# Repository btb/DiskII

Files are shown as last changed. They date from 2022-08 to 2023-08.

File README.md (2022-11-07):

# DiskII
 An Apple Disk II controller clone using standard EPROMs

Revision 0 of this board is broken, [here's how to fix it](https://github.com/btb/DiskII/wiki/Revision-0-errata).

[Revision 1](https://github.com/btb/DiskII/releases/tag/rev1) has all known problems fixed.

[Interactive BOM](https://btb.github.io/DiskII/bom/DiskII_rev1.html)

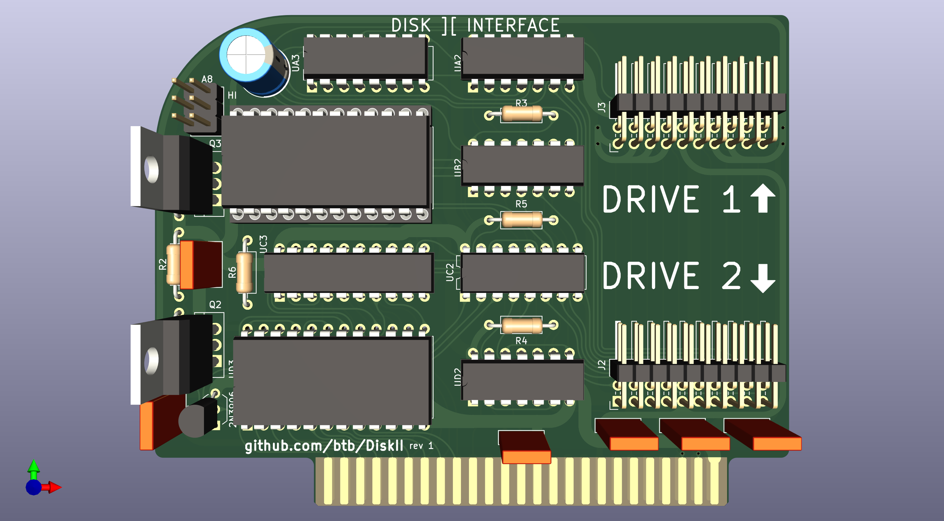
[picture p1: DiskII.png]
image info


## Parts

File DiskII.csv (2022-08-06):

Ref | Qnty | Value | Cmp name | Footprint | Description | Vendor
C1, C3, C4, C5, C6, C7, | 6 | .1uF | C_Small | Capacitor_THT:C_Rect_L7.0mm_W2.0mm_P5.00mm | Unpolarized capacitor, small symbol
C2, | 1 | 22uF | C_Polarized_US | Capacitor_THT:CP_Radial_D8.0mm_P5.00mm | Polarized capacitor, US symbol
J1, | 1 | Apple II Expansion Bus | Conn_02x25_Counter_Clockwise | Apple2:Apple II Expansion Edge Connector | Generic connector, double row, 02x25, counter clockwise pin numbering scheme (similar to DIP packge numbering), script generated (kicad-library-utils/schlib/autogen/connector/)
J2, | 1 | DRIVE 2 | Conn_02x10_Odd_Even_2 | Connector_PinHeader_2.54mm:PinHeader_2x10_P2.54mm_Horizontal | Generic connector, double row, 02x10, odd/even pin numbering scheme (row 1 odd numbers, row 2 even numbers), script generated (kicad-library-utils/schlib/autogen/connector/)
J3, | 1 | DRIVE 1 | Conn_02x10_Odd_Even_1 | Connector_PinHeader_2.54mm:PinHeader_2x10_P2.54mm_Horizontal | Generic connector, double row, 02x10, odd/even pin numbering scheme (row 1 odd numbers, row 2 even numbers), script generated (kicad-library-utils/schlib/autogen/connector/)
Q1, | 1 | 2N3906 | 2N3906 | Package_TO_SOT_THT:TO-92_Inline_Wide | -0.2A Ic, -40V Vce, Small Signal PNP Transistor, TO-92
Q2, Q3, | 2 | MPSU51 | MPSA92_1 | Package_TO_SOT_THT:TO-220-3_Vertical | 0.5A Ic, 300V Vce, PNP High Voltage Transistor, TO-92
R1, | 1 | 150 | R_US | Resistor_THT:R_Axial_DIN0207_L6.3mm_D2.5mm_P7.62mm_Horizontal | Resistor, US symbol
R2, | 1 | 68 | R_US | Resistor_THT:R_Axial_DIN0207_L6.3mm_D2.5mm_P7.62mm_Horizontal | Resistor, US symbol
R3, R7, | 2 | 3K | R_US | Resistor_THT:R_Axial_DIN0207_L6.3mm_D2.5mm_P7.62mm_Horizontal | Resistor, US symbol
R4, | 1 | 1M | R_US | Resistor_THT:R_Axial_DIN0309_L9.0mm_D3.2mm_P12.70mm_Horizontal | Resistor, US symbol
R5, | 1 | 49K | R_US | Resistor_THT:R_Axial_DIN0309_L9.0mm_D3.2mm_P12.70mm_Horizontal | Resistor, US symbol
R6, | 1 | 560 | R_US | Resistor_THT:R_Axial_DIN0207_L6.3mm_D2.5mm_P7.62mm_Horizontal | Resistor, US symbol
SW1, | 1 | A8 | SW_DPDT_x2 | Connector_PinHeader_2.54mm:PinHeader_2x03_P2.54mm_Vertical | Switch, dual pole double throw, separate symbols
SW2, | 1 | A9 | SW_DPDT_x2 | Connector_PinHeader_2.54mm:PinHeader_2x03_P2.54mm_Vertical | Switch, dual pole double throw, separate symbols
SW3, | 1 | A10 | SW_DPDT_x2 | Connector_PinHeader_2.54mm:PinHeader_2x03_P2.54mm_Vertical | Switch, dual pole double throw, separate symbols
UA2, | 1 | 74LS132 | 74LS132 | Package_DIP:DIP-14_W7.62mm | Quad 2-input NAND Schmitt trigger
UA3, | 1 | 74LS174 | 74LS174 | Package_DIP:DIP-16_W7.62mm | Hex D-type Flip-Flop, reset
UB2, | 1 | 74LS05 | 74LS05 | Package_DIP:DIP-14_W7.62mm | Inverter Open Collect
UB3, | 1 | 2758/16 P6 | 2758 | Package_DIP:DIP-24_W15.24mm | OTP EPROM 64 KiBit, [Obsolete 2004-01]
UC2, | 1 | 74LS259 | 74LS259_1 | Package_DIP:DIP-16_W7.62mm | 8-bit addressable latch
UC3, | 1 | 74LS323 | 74LS323 | Package_DIP:DIP-20_W7.62mm | 8-bit Universal Shift/Storage Register
UD2, | 1 | NE556 | NE556_1 | Package_DIP:DIP-14_W7.62mm | Dual Precision Timers, DIP-14/SOIC-14
UD3, | 1 | 2758/16 P5 | 2716 | Package_DIP:DIP-24_W15.24mm | OTP EPROM 64 KiBit, [Obsolete 2004-01]

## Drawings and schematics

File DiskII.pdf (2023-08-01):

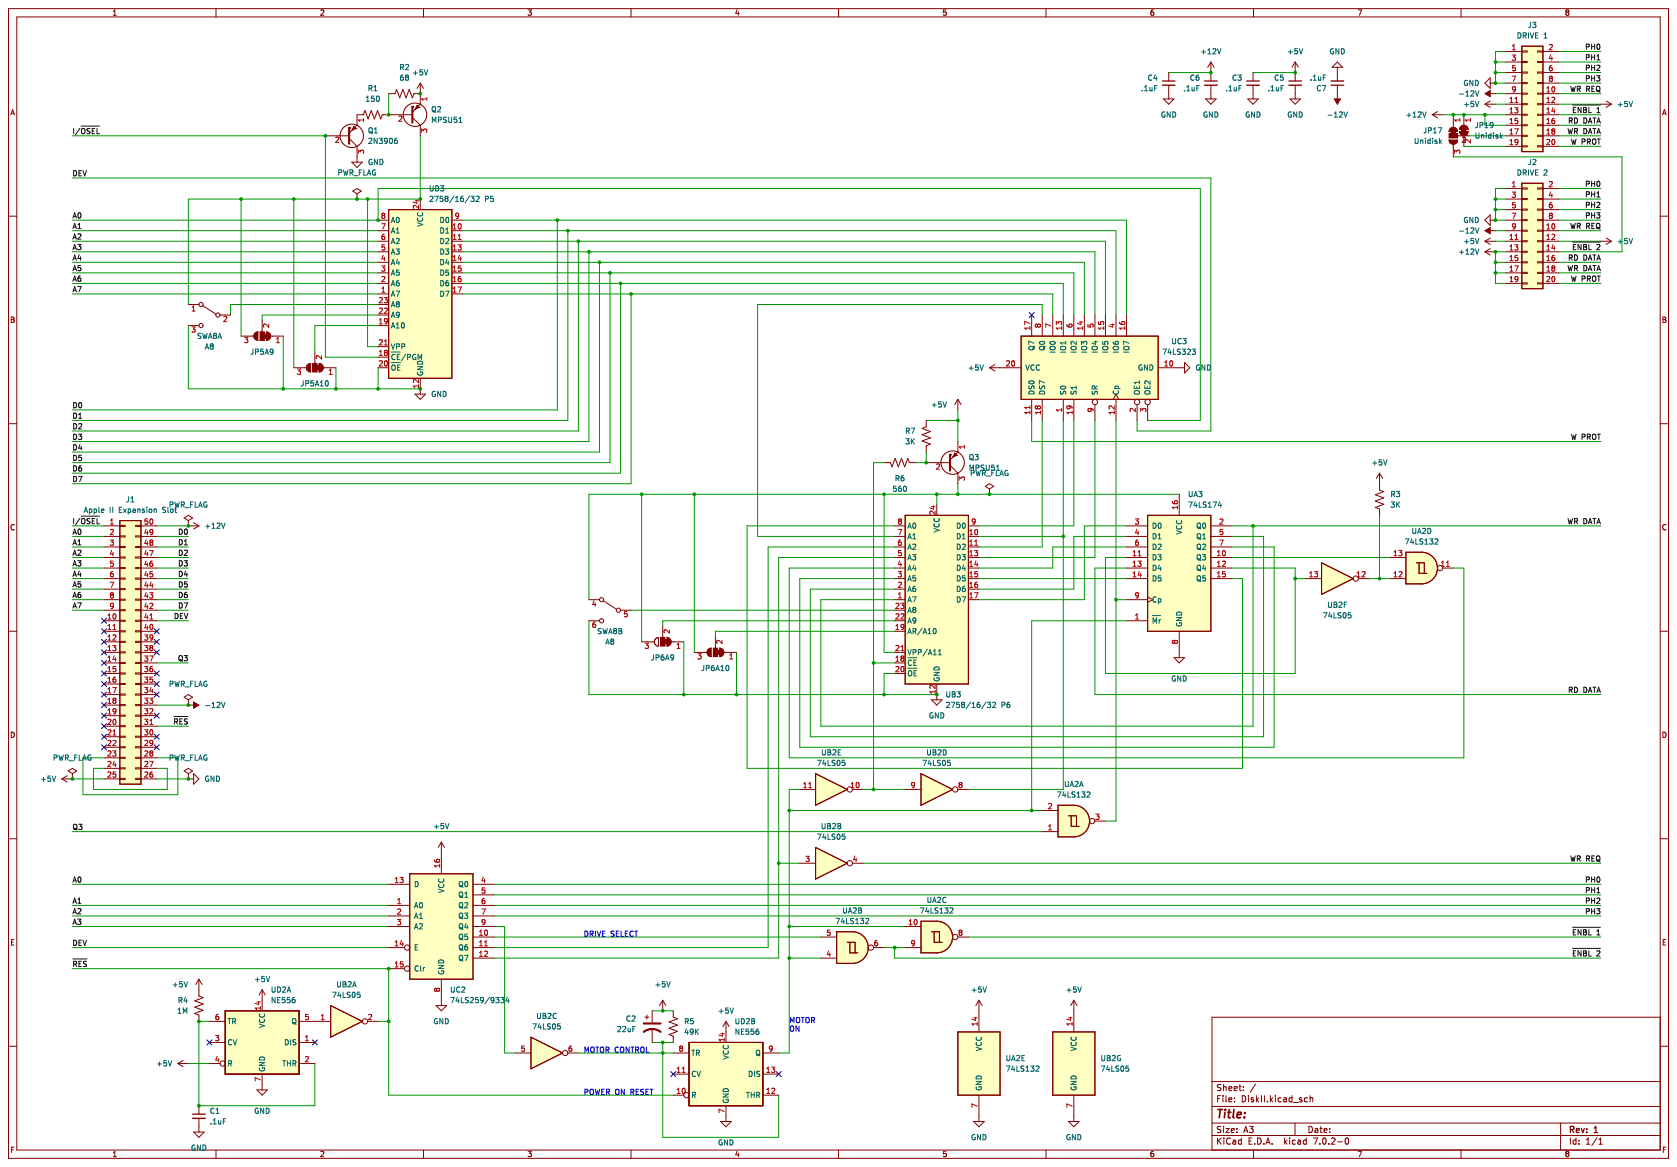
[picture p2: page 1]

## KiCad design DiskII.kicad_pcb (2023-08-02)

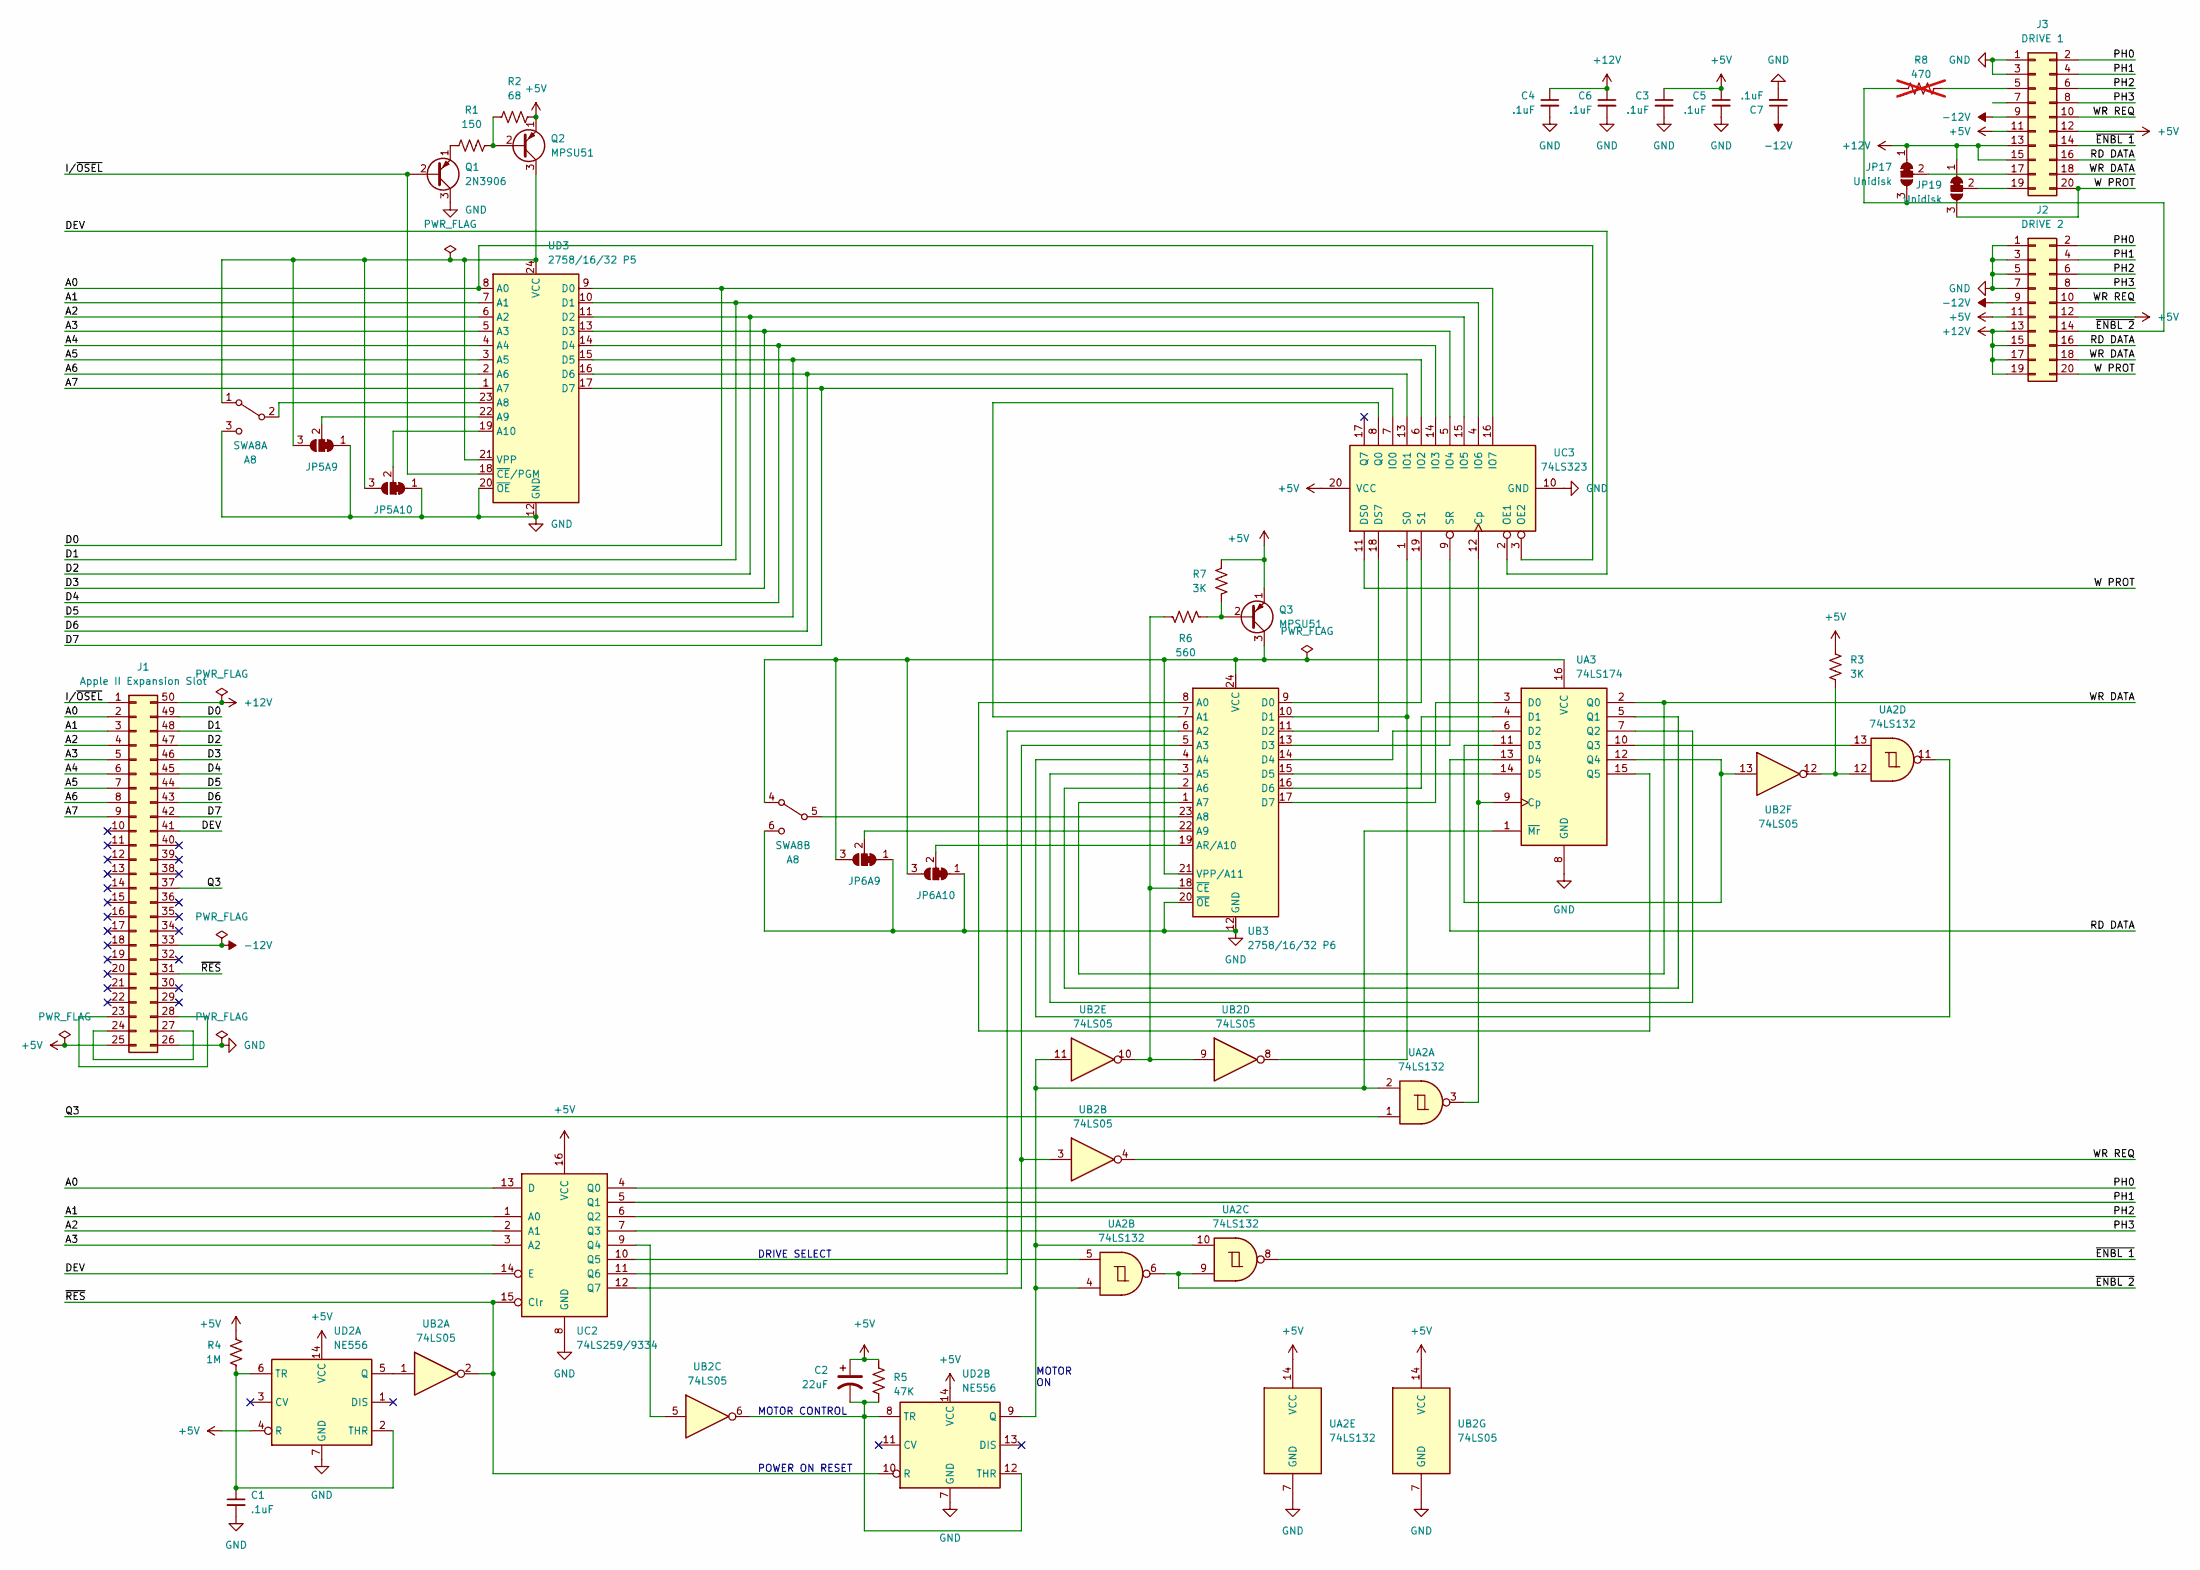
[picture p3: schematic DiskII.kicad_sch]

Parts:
C1, C3, C4, C5, C6, C7: .1uF; C_Rect_L7.0mm_W2.0mm_P5.00mm
C2: 22uF; CP_Radial_D8.0mm_P5.00mm
J1: Apple II Expansion Slot; Apple II Expansion Edge Connector
J2: DRIVE 2; PinHeader_2x10_P2.54mm_Horizontal
J3: DRIVE 1; PinHeader_2x10_P2.54mm_Horizontal
JP5A9, JP6A9: A9; SolderJumper-3_P1.3mm_Bridged12_RoundedPad1.0x1.5mm_NumberL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
JP5A10, JP6A10: A10; SolderJumper-3_P1.3mm_Bridged12_RoundedPad1.0x1.5mm_NumberL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
JP17, JP19: Unidisk; SolderJumper-3_P1.3mm_Bridged12_RoundedPad1.0x1.5mm
Q1: 2N3906; TO-92_Inline_Wide
Q2, Q3: MPSU51; TO-220-3_Vertical
R1: 150; R_Axial_DIN0207_L6.3mm_D2.5mm_P10.16mm_Horizontal
R2: 68; R_Axial_DIN0207_L6.3mm_D2.5mm_P10.16mm_Horizontal
R3, R7: 3K; R_Axial_DIN0207_L6.3mm_D2.5mm_P10.16mm_Horizontal
R4: 1M; R_Axial_DIN0207_L6.3mm_D2.5mm_P10.16mm_Horizontal
R5: 47K; R_Axial_DIN0207_L6.3mm_D2.5mm_P10.16mm_Horizontal
R6: 560; R_Axial_DIN0207_L6.3mm_D2.5mm_P10.16mm_Horizontal
R8: 470; R_Axial_DIN0207_L6.3mm_D2.5mm_P10.16mm_Horizontal; not fitted
SWA8: A8; PinHeader_2x03_P2.54mm_Vertical
UA2: 74LS132; DIP-14_W7.62mm
UA3: 74LS174; DIP-16_W7.62mm
UB2: 74LS05; DIP-14_W7.62mm
UB3: 2758/16/32 P6; DIP-24_W15.24mm
UC2: 74LS259/9334; DIP-16_W7.62mm
UC3: 74LS323; DIP-20_W7.62mm
UD2: NE556; DIP-14_W7.62mm
UD3: 2758/16/32 P5; DIP-24_W15.24mm

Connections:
+5V: C2.1, C3.1, C5.1, J1.25, J2.11, J2.12, J3.11, J3.12, Q2.1 (E), Q3.1 (E), R2.1, R3.1, R4.1, R5.2, R7.1, UA2.14 (VCC), UB2.14 (VCC), UC2.16 (VCC), UC3.20 (VCC), UD2.4 (R), UD2.14 (VCC)
+12V: C4.1, C6.1, J1.50, J2.13, J2.15, J2.17, J2.19, J3.13, J3.15, JP17.1 (A), JP19.1 (A)
-12V: C7.1, J1.33, J2.9, J3.9
/A0: J1.2, UC2.13 (D), UC3.3 (OE2), UD3.8 (A0)
/A1: J1.3, UC2.1 (A0), UD3.7 (A1)
/A2: J1.4, UC2.2 (A1), UD3.6 (A2)
/A3: J1.5, UC2.3 (A2), UD3.5 (A3)
/A4: J1.6, UD3.4 (A4)
/A5: J1.7, UD3.3 (A5)
/A6: J1.8, UD3.2 (A6)
/A7: J1.9, UD3.1 (A7)
/D0: J1.49, UC3.16 (IO7), UD3.9 (D0)
/D1: J1.48, UC3.4 (IO6), UD3.10 (D1)
/D2: J1.47, UC3.15 (IO5), UD3.11 (D2)
/D3: J1.46, UC3.5 (IO4), UD3.13 (D3)
/D4: J1.45, UC3.14 (IO3), UD3.14 (D4)
/D5: J1.44, UC3.6 (IO2), UD3.15 (D5)
/D6: J1.43, UC3.13 (IO1), UD3.16 (D6)
/D7: J1.42, UC3.7 (IO0), UD3.17 (D7)
/DEV: J1.41, UC2.14 (E), UC3.2 (OE1)
/I/~OSEL: J1.1, Q1.2 (B), UD3.18 (~CE/PGM)
/PH0: J2.2, J3.2, UC2.4 (Q0)
/PH1: J2.4, J3.4, UC2.5 (Q1)
/PH2: J2.6, J3.6, UC2.6 (Q2)
/PH3: J2.8, J3.8, UC2.7 (Q3)
/Q3: J1.37, UA2.1
/RD DATA: J2.16, J3.16, UA3.13 (D4)
/W PROT: J2.20, J3.20, JP19.3 (B), UC3.11 (DS0)
/WR DATA: J2.18, J3.18, UA3.2 (Q0), UB3.1 (A7)
/WR REQ: J2.10, J3.10, UB2.4
/~ENBL 1: J3.14, UA2.8
/~ENBL 2: J2.14, JP17.3 (B), R8.1, UA2.6, UA2.9
/~RES: J1.31, UB2.2, UC2.15 (Clr), UD2.10 (R)
GND: C1.2, C3.2, C4.2, C5.2, C6.2, C7.2, J1.26, J2.1, J2.3, J2.5, J2.7, J3.1, J3.3, J3.5, J3.7, JP5A9.1 (A), JP5A10.1 (A), JP6A9.1 (A), JP6A10.1 (A), Q1.3 (C), R8.2, SWA8.3 (C), SWA8.6 (C), UA2.7 (GND), UA3.8 (GND), UB2.7 (GND), UB3.12 (GND), UB3.20 (~OE), UC2.8 (GND), UC3.10 (GND), UD2.7 (GND), UD3.12 (GND), UD3.20 (~OE)
unnamed: JP5A9.3 (B), JP5A10.3 (B), Q2.3 (C), SWA8.1 (A), UD3.21 (VPP), UD3.24 (VCC)
unnamed: JP6A9.3 (B), JP6A10.3 (B), Q3.3 (C), SWA8.4 (A), UA3.16 (VCC), UB3.21 (VPP/A11), UB3.24 (VCC)
unnamed: J1.23, J1.28
unnamed: J1.24, J1.27
unnamed: J3.17, JP17.2 (C)
unnamed: J3.19, JP19.2 (C)
unnamed: JP5A9.2 (C), UD3.22 (A9)
unnamed: JP5A10.2 (C), UD3.19 (A10)
unnamed: JP6A9.2 (C), UB3.22 (A9)
unnamed: JP6A10.2 (C), UB3.19 (AR/A10)
unnamed: Q1.1 (E), R1.1
unnamed: Q2.2 (B), R1.2, R2.2
unnamed: Q3.2 (B), R6.1, R7.2
unnamed: R3.2, UA2.12, UB2.12
unnamed: SWA8.2 (B), UD3.23 (A8)
unnamed: SWA8.5 (B), UB3.23 (A8)
unnamed: UA2.3, UA3.9 (Cp), UC3.12 (Cp)
unnamed: UA3.3 (D0), UB3.17 (D7)
unnamed: UA3.4 (D1), UB3.16 (D6)
unnamed: UA3.6 (D2), UB3.14 (D4)
unnamed: UA3.11 (D3), UA3.12 (Q4), UB2.13
unnamed: UA3.14 (D5), UB3.15 (D5)
unnamed: UA3.5 (Q1), UB3.2 (A6)
unnamed: UA3.7 (Q2), UB3.3 (A5)
unnamed: UA2.13, UA3.10 (Q3)
unnamed: UA3.15 (Q5), UB3.8 (A0)
unnamed: UA2.2, UA2.4, UA2.10, UA3.1 (~Mr), UB2.11, UD2.9 (Q)
unnamed: UB3.7 (A1), UC3.8 (Q0)
unnamed: UB3.6 (A2), UC2.11 (Q6)
unnamed: UB2.3, UB3.5 (A3), UC2.12 (Q7)
unnamed: UA2.11, UB3.4 (A4)
unnamed: UB3.9 (D0), UC3.19 (S1)
unnamed: UB2.8, UB3.10 (D1), UC3.1 (S0)
unnamed: UB3.11 (D2), UC3.18 (DS7)
unnamed: UB3.13 (D3), UC3.9 (SR)
unnamed: R6.2, UB2.9, UB2.10, UB3.18 (~CE)
unnamed: UB2.5, UC2.9 (Q4)
unnamed: UA2.5, UC2.10 (Q5)
unnamed: UB2.1, UD2.5 (Q)
unnamed: C1.1, R4.2, UD2.2 (THR), UD2.6 (TR)
unnamed: C2.2, R5.1, UB2.6, UD2.8 (TR), UD2.12 (THR)

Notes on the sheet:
MOTOR ON
POWER ON RESET
DRIVE SELECT
MOTOR CONTROL

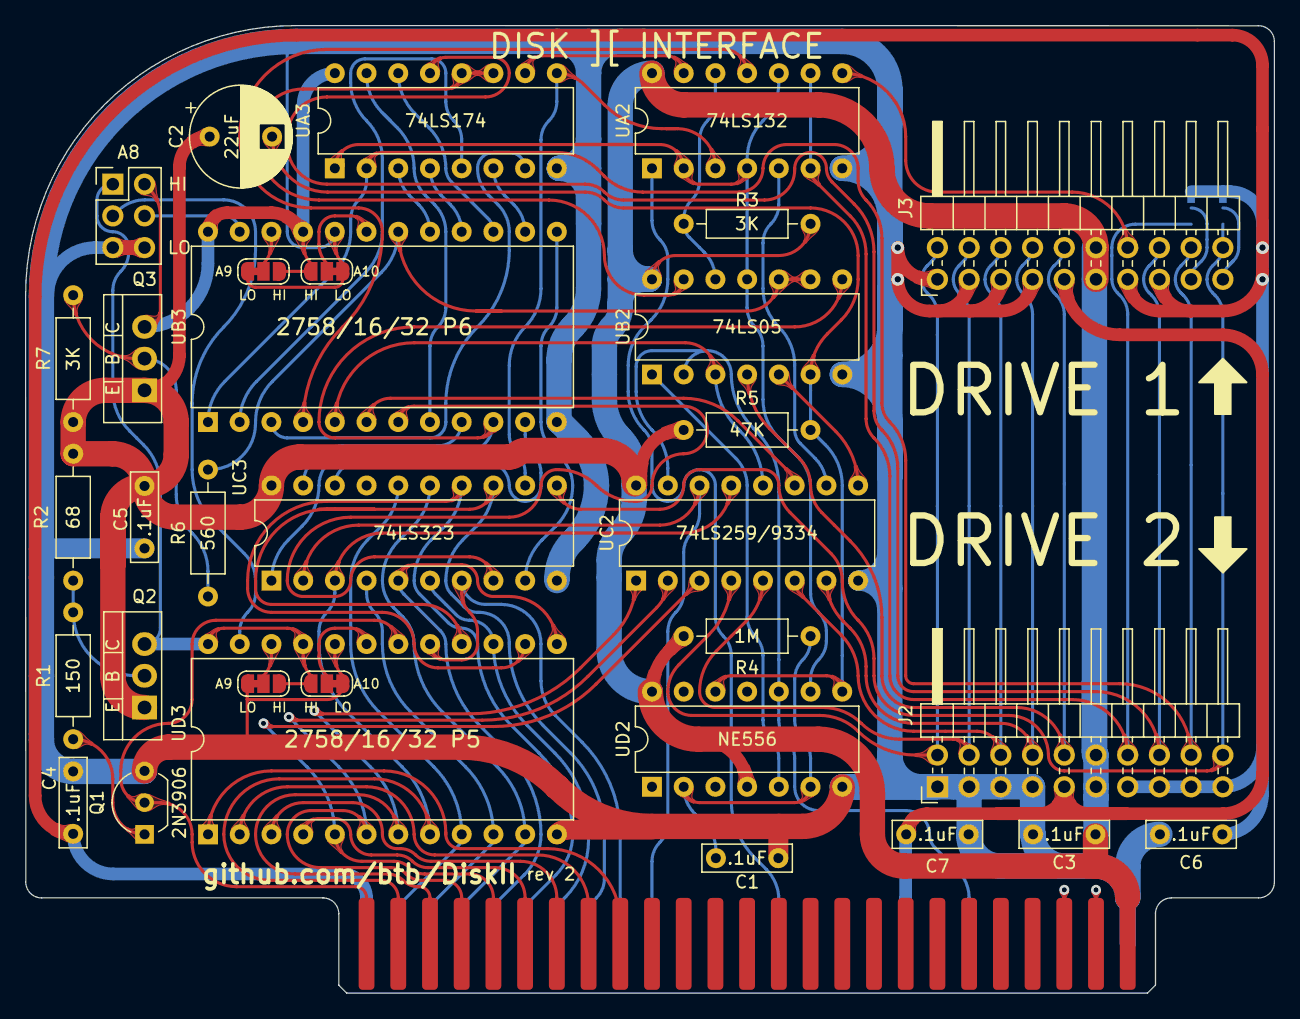
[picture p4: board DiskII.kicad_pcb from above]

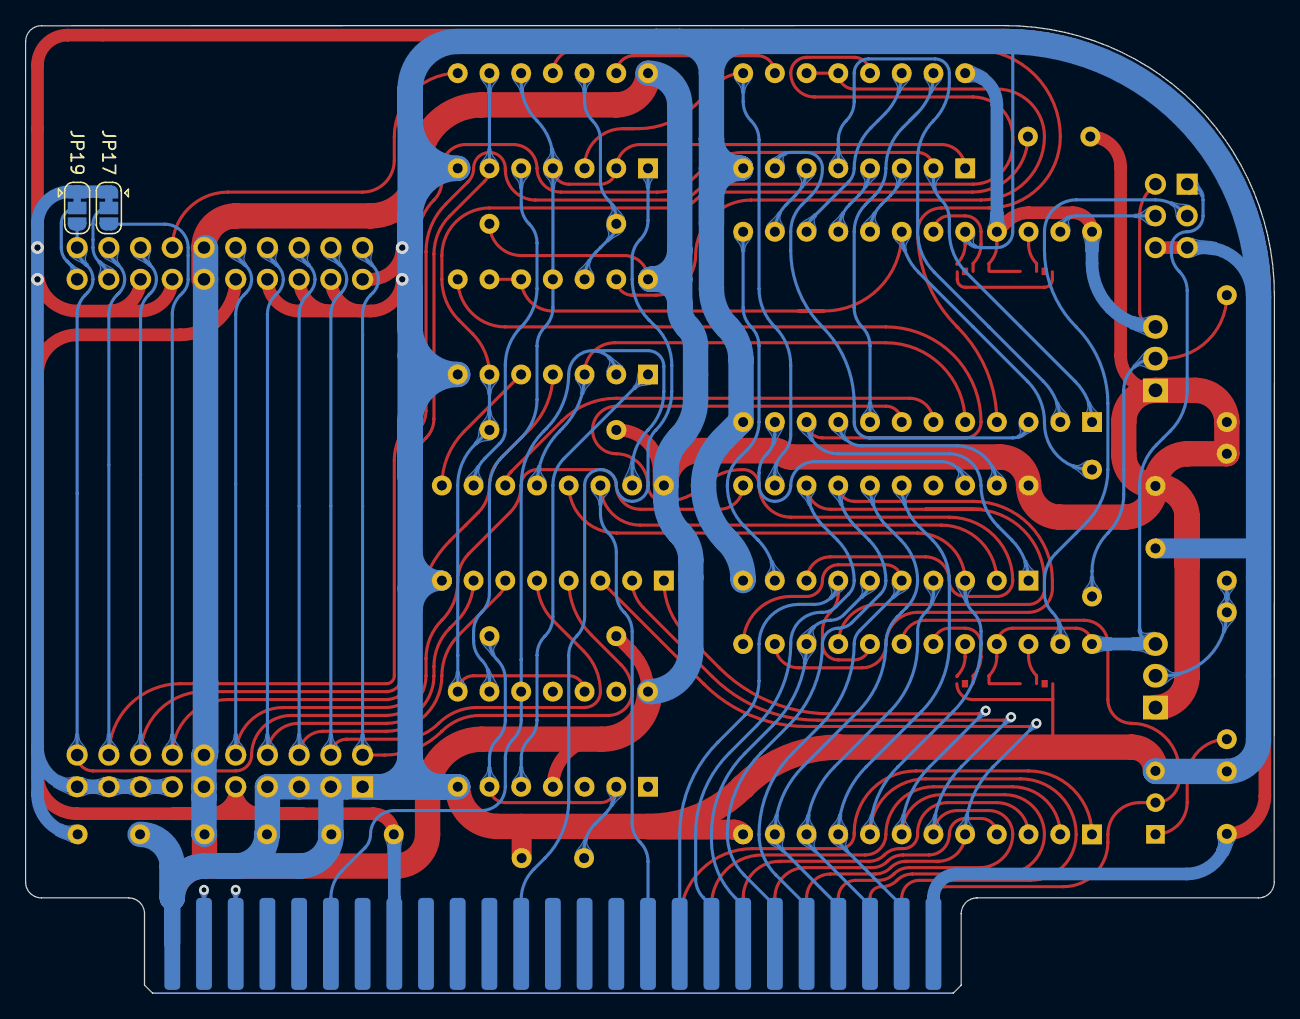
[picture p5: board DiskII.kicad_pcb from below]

Board: 2 copper layers, 100.0 x 77.5 mm, 35 parts (2 on the bottom side), 75 nets.

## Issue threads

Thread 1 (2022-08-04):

Status so far?

mengstr, 2022-08-04:
Hi Bradley,

I just got an Apple // again after 40 years and unfortunately it was without a drive and the disk controller card. (I've already got an Apple drive without the enclosure that I bought by mistake a while back.) So I was just about to make some prototype cards so I could make a clone of the Disk II card myself doing the same as you - using regular eproms which of I have a metric crapton of. But then I saw your card at Adrians Digital Basement on YT and realised that why should I design it myself when there's something already out there.

You mention in the readme that this is a WIP - so I wonder how WIPpy is it? Do you recon It at least kinda works even if some greenwiring would be necessary?

btb, 2022-08-05:
It really should work, it's very close to an exact copy of Apple's card. I simply haven't tested it myself yet due to not yet having a floppy drive or a floppy emulator to plug into it (I'm planning to build an SDisk II) and all of my free time is very limited at the moment.

mengstr, 2022-08-05:
Then I'll give it a go. The only real issue is that the '323 is hard - not to say impossible - to find from any of the usual resellers like Farnell/Element14, Mouser, Digikey or TME. But they're at least available on eBay...

btb, 2022-08-06:
> Then I'll give it a go. The only real issue is that the '323 is hard - not to say impossible - to find from any of the usual resellers like Farnell/Element14, Mouser, Digikey or TME. But they're at least available on eBay...

My favorite seller for items like that is https://unicornelectronics.com

mengstr, 2022-08-06:
They definitely have a lot of nice retro stuff there. But it will end up costing me a bundle in total to get the chips from there, $30 minimum order + overseas shipping, $8 import processing fee and then some local VAT on top of all this.

I found a EU-based (Bulgaria) seller on ebay and got a pack of 10 of the 323's for $6.  Of course I added some USSR variants of the 8080 CPU, and some other interesting 1970's ICs and a tub of 1000 core memory ferrite cores as well ;)

mengstr, 2022-08-27:
I received my PCBs today and soldered up one. I didn't have any 2-row RA connector so a normal one had to suffice. I also jumpered everything related to power save modes and the EPROM banks.

So tomorrow I try find the contents of the eproms and burn them and give it a go in my Apple 2e...  You don't happen to have the eprom bins/hexes available do you?

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

btb, 2022-08-28:
The images are here: https://mirrors.apple2.org.za/Apple%20II%20Documentation%20Project/Interface%20Cards/Disk%20Drive%20Controllers/Apple%20Disk%20II%20Interface%20Card/ROM%20Images/

You can map them into your EPROMs at whatever addresses you like, just set the a8, a9, a10 jumpers accordingly.

veremenko-y, 2022-09-21:
I'm kinda curious about the status of this as well :)

btb, 2022-10-20:
I finally got a real disk drive to test with, and this design does indeed have a fatal flaw. I'll put up some instructions for fixing it.

btb, 2022-10-20:
I've described the problem and how to fix it here:
https://github.com/btb/DiskII/wiki/Revision-0-errata

Closed 2023-04-25.

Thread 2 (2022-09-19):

Files to burn to Eproms and Jumper functions

asapreta, 2022-09-19:
Hi!
Where do I can find the contents for the 2716 Eproms? Are they the same as prom5 and prom6?

Also, what are the jumpers for?

Thank you!

mengstr, 2022-09-21:
I downloaded my images from  https://mirrors.apple2.org.za/Apple%20II%20Documentation%20Project/Interface%20Cards/Disk%20Drive%20Controllers/Apple%20Disk%20II%20Interface%20Card/ROM%20Images/

btb, 2022-09-22:
The jumpers just go directly to your eprom's extra address lines, A8, A9 and A10, and you set them high or low to select the region of the eprom where you have placed the desired firmware.

asapreta, 2022-09-22:
> I downloaded my images from https://mirrors.apple2.org.za/Apple%20II%20Documentation%20Project/Interface%20Cards/Disk%20Drive%20Controllers/Apple%20Disk%20II%20Interface%20Card/ROM%20Images/

Thank you, I thought I need to be something diferent (code or so) to use on regular EEPROMs!

asapreta, 2022-09-22:
> The jumpers just go directly to your eprom's extra address lines, A8, A9 and A10, and you set them high or low to select the region of the eprom where you have placed the desired firmware.

So, as the code is "small" we can have different codes in the same IC, right? Interesting feature.

asapreta, 2022-09-22:
And, I don't know why this project isn't popular. Do people think it won't work?

btb, 2022-09-22:
I myself haven't gotten to test it yet (no disk drives), but it should work. @mengstr is your board working now?

asapreta, 2022-09-22:
My main doubt was about the code to write in the EEPROMs as they are the same of the PROMs I will send the gerber to create the board and test it.

btb, 2022-10-20:
I have built and tested my board, and it doesn't work without some rewiring, which I added to the wiki here: https://github.com/btb/DiskII/wiki/Revision-0-errata

After rewiring, I tested it successfully using the 16 sector firmware that @mengstr linked above.

asapreta, 2022-10-20:
> I have built and tested my board, and it doesn't work without some rewiring, which I added to the wiki here: https://github.com/btb/DiskII/wiki/Revision-0-errata
>
> After rewiring, I tested it successfully using the 16 sector firmware that @mengstr linked above.

Thanks for all the information and testing.
I will try to redesign the board with your fixes.

When you mention unscrambled 16 sector firwmare, we have to change anything from the ones @mengstr linked from Asimov, or just burn to a regular eeprom?

Thank you!

btb, 2022-10-20:
No changes needed to the firmware, just make sure you set the jumpers A8 A9 A10 as appropriate (i.e. all LO, assuming you put the .bin files at offset 0 in the EPROM)

btb, 2022-10-20:
The kicad project is now updated with correct wiring as well. I haven't updated the gerbers because I want to make some other changes  before I release it as "revision 1"

asapreta, 2022-10-20:
> No changes needed to the firmware, just make sure you set the jumpers A8 A9 A10 as appropriate (i.e. all LO, assuming you put the .bin files at offset 0 in the EPROMs)

> The kicad project is now updated with correct wiring as well. I haven't updated the gerbers because I want to make some other changes before I release it as "revision 1"

Well, this project is evolving a lot. Thank you.
I will wait for the updated gerbers then!

btb, 2022-11-07:
Revision 1 is now, done, with gerbers here: https://github.com/btb/DiskII/releases/tag/rev1

asapreta, 2022-11-08:
> Revision 1 is now, done, with gerbers here: https://github.com/btb/DiskII/releases/tag/rev1

Thank you very much.
I will make a batch for me. There are some APII needing them here!

btb, 2022-11-08:
> Thank you very much. I will make a batch for me. There are some APII needing them here!

Great! Let me know how it goes, and check my notes here regarding the parts you need: https://github.com/btb/DiskII/wiki/Materials-Needed

Daniel102010, 2023-01-04:
Hello from Ireland, I have ordered few PCB rev.1 but unfortunately didn’t work for me. When I power on my Apple IIe the computer beeps and jumps on the Applesoft Basic. Any idea? Thanks in advance

btb, 2023-01-06:
> Hello from Ireland, I have ordered few PCB rev.1 but unfortunately didn’t work for me. When I power on my Apple IIe the computer beeps and jumps on the Applesoft Basic. Any idea? Thanks in advance

Sure. So you have a bootable disk in the drive and you're trying to boot from that? Does it boot from basic with "PR#6"? Can you send a photo of your board?

asapreta, 2023-01-06:
> Hello from Ireland, I have ordered few PCB rev.1 but unfortunately didn’t work for me. When I power on my Apple IIe the computer beeps and jumps on the Applesoft Basic. Any idea? Thanks in advance

Without disks the Apple should hang in the Apple ][ (or Apple //e) logo screen and wait until a disk is present in the drive or a CTRL+RESET is done to go to basic.

Your card seems not being recognized.

Daniel102010, 2023-01-06:
Hi, thanks for reply I'm not at home right now but I have some pictures on my phone of my phone with the card.
How I have tested: I plugged it in Slot 6 with not disk drive just the card and no other cards present. I turn on the computer and I expect to wait for disk drive but instead just jump into AppleSoft Basic ( same thing as no card plugged at all)
At this point I have tried to PR#6 just hanging.
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

Daniel102010, 2023-01-06:
I forgot to mention all the IC are plugged out from tested and fully working Card I can't suspect any of them are bad.

Daniel102010, 2023-01-11:
I have found the problem was my fault I setup the jumpers wrong, after connecting the jumpers correctly everything works flawlessly.

btb, 2023-01-11:
oh, that's great to know. I'm curious what parts did you end up using for Q2 and Q3? and that pair of resistors on the left, I'm guessing you put two in parallel because you didn't have the right value on hand?

Daniel102010, 2023-01-11:
I use 2N3906 and BD140 and yes I don't have 68 ohms resistor and I use two resistors in series 47 ohms and 22 ohms to make a close to 68 ohms

asapreta, 2023-01-12:
>

As our friend had problems with the jumpers, is It possible to creste a table of their positions/selection?
Thanks in advance

StormTrooper, 2023-07-31:
Very interesting project this. Just a note on the DiskII.pdf - it's out of date and does not match with the KiCad schematic.

Trying to troubleshoot a build that is not booting up and the pdf confused me :)

btb, 2023-08-01:
I just noticed that myself - fixed now

btb, 2023-08-02:
> The corect jumper's setup when you're put the bin files in the lower part of the EPROM are exactly like in the pictures below [...]

If you don't want to have to do that bodge on pin 21 of a 2732 EPROM, you can just put the code in the upper half (i.e., from 0800 to 08FF) - I always just do repeating copies of the code to fill up the whole thing anyway.
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
btb, 2024-10-13:
@vibr77
There is no need to do anything with the solder pads under the ROMs, unless you need to use the upper parts of the address space for some reason.

Can you link to a datasheet or more info on the transistors you used? The only info I find for BD140 and BD140G appears to show pin order of ECB or BCE, but the pin order of the MPS-U51 is EBC.

Until someone finds a good reason it should be necessary to use such high-power parts, I recommend just using the simple 2n3906 instead. It has the same pinout and appears to work fine.

mengstr, 2024-10-13:
Are the transistors actually necessary at all? As far as I remember they just turn the VCC off for some of the ICs to reduce power consumption when the disk is not in active use.  Maybe I'm wrong here - it's not like Woz to add parts that really could have been "Muntzed" away.

btb, 2024-10-13:
As far as I know, no. https://github.com/btb/DiskII/wiki/Materials-Needed

mengstr, 2024-10-13:
I tend to forget checking out the wikis far too often... 🤣

aihk, 2024-11-16:
> 一些图片来说明我的意思： 我使用W27c512临时补丁，因为我的2716闪存芯片太慢，所以我需要更换它们（150ns） 我使用BD-140作为MPSU51替代品（也带有补丁）。 这是我的 DISK-II 模拟器，屏幕上显示“track 0”： ![图像](https://private-user-images.githubusercontent.com/54148615/352817057-e7e74974-962e-4ad0-8d39-02102c4bb6cc.png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) ![图像](https://private-user-images.githubusercontent.com/54148615/352817137-8310f4ff-13bc-4185-9807-3b1e48a7dde4.png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) ![图像](https://private-user-images.githubusercontent.com/54148615/352817191-9692764a-e787-423d-bb07-1880267a0682.png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) ![图像](https://private-user-images.githubusercontent.com/54148615/352817236-e5c42010-bbec-4acf-98c3-25025319cb31.png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)

Have you solved this problem? My situation is the same as yours.

general-ackbar, 2025-03-20:
>
> Have you solved this problem? My situation is the same as yours.

I had the same problem, where the Disk ][ Interface didn't move tracks (same situaiton as described by @msx-solis & @aihk  ). In my case it was either a defect NE556 or a faulty PNP at Q3 (I can say which as I replaced Q2 and Q3 with 2n3906s and the NE556 at the same time)

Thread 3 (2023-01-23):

R5 value

soboth, 2023-01-23:
Looking at original schematics for Disk II interface, R5 seems to be 47KΩ not 49KΩ as per your design. Moreover 49K is practically impossible to find in the contrary to 47K.

btb, 2023-01-23:
Indeed it is, I think that has to have been a typo. 47k is what I used in my builds.

soboth, 2023-01-23:
Cool, thanks! That was my assumption as the rest of resistors have value as per original design. Although it's a minor issue to me, you might think of correcting the silkscreen and BOM.

btb, 2023-01-24:
yep, it'll be fixed in next revision. thanks!

Closed 2023-01-23.

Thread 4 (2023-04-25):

Error in the errata :)

mengstr, 2023-04-25:
I finally started to apply the bugfix you described in the errata. But it seems like the new connections on the lower row of the EPROM are shifted one step to the left. What is designated as D2 is really the GND pin.

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

btb, 2023-05-22:
😭

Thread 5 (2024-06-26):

Update Interactive BOM and other documents

jgauchia, 2024-06-26:
Hi , I see in sch file that value of R5 whas changed from 49K to 47K.

Please can you update Interactive BOM and other document related (PDF schematic, etc... ) with the latest KiCad schematic.

Thank you

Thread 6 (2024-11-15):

2716 EPROM question

aihk, 2024-11-15:
When 2176 uses the default OL jumper, where is it placed in the EPROM?
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

I am using the TL866II Plus programmer. Is it placed in the position shown in the picture?

Closed 2024-11-24.

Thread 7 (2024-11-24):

Soft drive card failure

aihk, 2024-11-24:
Soft drive card failure

The soft drive card will be executed automatically. But it will make an error. There is an error in acquaintance

I uploaded pictures

Sorry, English is not my mother tongue. The machine translation I use
![Uploading IMG_6771.JPG…]()

aihk, 2024-11-24:
![Uploading IMG_6771.JPG…]()

Closed 2024-11-24.

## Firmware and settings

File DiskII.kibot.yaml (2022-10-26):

kibot:
  version: 1

global:
  filters:
  - number: 1007
  - number: 1015
  - number: 58

filters:
- name: only_jlc_parts
  comment: Only parts with JLC (LCSC) code
  type: generic
  include_only:
  - column: LCSC#
    regex: ^C\d+

variants:
- name: place_holder
  comment: Just a place holder for pre_transform filters
  type: kicost
  pre_transform:
  - _kicost_rename
  - _rot_footprint

preflight:
  run_drc: true
  run_erc: true

outputs:
- name: basic_boardview
  comment: Board View export
  type: boardview
  dir: Assembly
- name: generic_bom_html
  comment: Generic Bill of Materials in HTML format
  type: bom
  dir: BoM/Generic
  options:
    format: HTML
    count_smd_tht: true
- name: generic_bom_csv
  comment: Generic Bill of Materials in CSV format
  type: bom
  dir: BoM/Generic
  options:
    format: CSV
    count_smd_tht: true
- name: generic_bom_txt
  comment: Generic Bill of Materials in TXT format
  type: bom
  dir: BoM/Generic
  options:
    format: TXT
    count_smd_tht: true
- name: generic_bom_tsv
  comment: Generic Bill of Materials in TSV format
  type: bom
  dir: BoM/Generic
  options:
    format: TSV
    count_smd_tht: true
- name: generic_bom_xml
  comment: Generic Bill of Materials in XML format
  type: bom
  dir: BoM/Generic
  options:
    format: XML
    count_smd_tht: true
- name: generic_bom_xlsx
  comment: Generic Bill of Materials in XLSX format
  type: bom
  dir: BoM/Generic
  options:
    format: XLSX
    count_smd_tht: true
- name: positional_bom_html
  comment: Positional Bill of Materials in HTML format
  type: bom
  dir: BoM/Positional
  options:
    format: HTML
    columns: &id001
    - Row
    - Description
    - Part
    - Part Lib
    - References
    - Value
    - Footprint
    - Footprint Lib
    - Quantity Per PCB
    - Build Quantity
    - Status
    - Datasheet
    - Sheetpath
    - Source BoM
    - Footprint X
    - Footprint Y
    - Footprint Rot
    - Footprint Side
    - Footprint Type
    - Footprint Populate
    - Footprint X-Size
    - Footprint Y-Size
    count_smd_tht: true
    html:
      style: modern-red
- name: positional_bom_xlsx
  comment: Positional Bill of Materials in XLSX format
  type: bom
  dir: BoM/Positional
  options:
    format: XLSX
    columns: *id001
    count_smd_tht: true
    xlsx:
      style: modern-red
- name: costs_bom_xlsx
  comment: Costs Bill of Materials in XLSX format
  type: bom
  dir: BoM/Costs
  options:
    format: XLSX
    count_smd_tht: true
    xlsx:
      style: modern-green
      kicost: true
      specs: true
    variant: place_holder
- name: macrofab_xyrs
  comment: Pick and place file, XYRS style
  type: bom
  options:
    variant: place_holder
    output: '%f_MacroFab.XYRS'
    units: mils
    group_fields: []
    sort_style: ref
    use_aux_axis_as_origin: true
    ignore_dnf: false
    footprint_populate_values: 0,1
    footprint_type_values: 1,2,0
    csv:
      separator: "\t"
      hide_pcb_info: true
      hide_stats_info: true
      hide_header: true
    columns:
    - field: References
      name: Designator
    - field: Footprint X
      name: X-Loc
    - field: Footprint Y
      name: Y-Loc
    - field: Footprint Rot
      name: Rotation
    - field: Footprint Side
      name: Side
    - field: Footprint Type
      name: Type
    - field: Footprint X-Size
      name: X-Size
    - field: Footprint Y-Size
      name: Y-Size
    - field: Value
    - field: Footprint
    - field: Footprint Populate
      name: Populate
  dir: Position
- name: basic_diff_pcb
  comment: PCB diff between the last two changes
  type: diff
  dir: diff
  layers:
  - layer: F.Cu
    suffix: F_Cu
    description: Front copper
  - layer: B.Cu
    suffix: B_Cu
    description: Bottom copper
  - layer: F.Silkscreen
    suffix: F_Silkscreen
    description: Front silkscreen (artwork)
  - layer: B.Mask
    suffix: B_Mask
    description: Bottom soldermask (negative)
  - layer: F.Mask
    suffix: F_Mask
    description: Front soldermask (negative)
  - layer: Edge.Cuts
    suffix: Edge_Cuts
    description: Board shape
  - layer: F.Courtyard
    suffix: F_Courtyard
    description: Front courtyard area
  - layer: F.Fab
    suffix: F_Fab
    description: Front documentation
  options:
    old: KIBOT_LAST-1
    old_type: git
    new: HEAD
    new_type: git
    cache_dir: ''
    add_link_id: true
- name: basic_diff_sch
  comment: Schematic diff between the last two changes
  type: diff
  dir: diff
  options:
    old: KIBOT_LAST-1
    old_type: git
    new: HEAD
    new_type: git
    cache_dir: ''
    add_link_id: true
    pcb: false
- name: basic_download_datasheets
  comment: Download the datasheets
  type: download_datasheets
  dir: Datasheets
- name: basic_dxf
  comment: Individual layers in DXF format
  type: dxf
  dir: Individual_Layers/DXF
  layers:
  - layer: F.Cu
    suffix: F_Cu
    description: Front copper
  - layer: B.Cu
    suffix: B_Cu
    description: Bottom copper
  - layer: F.Silkscreen
    suffix: F_Silkscreen
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

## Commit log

2022-08-03 add KiCad files
    [DiskII.kicad_pcb, DiskII.kicad_sch]
2022-08-03 add schematic pdf and gerber files
    [DiskII-B_Cu.gbr, DiskII-B_Mask.gbr, DiskII-B_Paste.gbr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]
2022-08-06 add BOM
    [DiskII.csv]
2022-08-06 Add Interactive BOM
2022-08-07 move text away from via
    [DiskII.kicad_pcb]
2022-08-07 update BOM
    [DiskII.kicad_pcb, DiskII.kicad_sch]
2022-10-20 fix misrouted data lines to shift register
    a few other minor fixes
    [DiskII.kicad_pcb, DiskII.kicad_sch]
2022-10-26 massive fixups
    [DiskII.kicad_pcb, DiskII.kicad_sch]
2022-11-07 revision 1
    [DiskII.kicad_pcb, DiskII.kicad_sch]
2022-11-07 revision 1 gerbers
    [DiskII-B_Cu.gbr, DiskII-B_Mask.gbr, DiskII-B_Paste.gbr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]
2022-11-07 no gerbers
    [DiskII-B_Cu.gbr, DiskII-B_Mask.gbr, DiskII-B_Paste.gbr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]
2022-11-08 BOM: no solder jumpers, hide fab layer by default
    [DiskII.kicad_pcb, DiskII.kicad_sch]
2023-08-01 rev1 schematic pdf
2023-08-01 jumper to put WPROT on pin 19
    [DiskII.kicad_pcb, DiskII.kicad_sch]
2023-08-02 starting rev 2
    [DiskII.kicad_pcb, DiskII.kicad_sch]
